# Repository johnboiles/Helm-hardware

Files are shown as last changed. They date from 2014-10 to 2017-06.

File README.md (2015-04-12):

Helm
====
Board to convert RayMarine Seatalk to NMEA 0183 and vice versa. Also provides a connector for a TTL GPS such as SparkFun part #11571. I use it with a Raspberry PI connected over USB to get boat data into OpenCPN.

BOM
---
* 2x DS89C21 Differential CMOS Line Driver
* 1x Sparkfun Pro Micro 5V/16MHz
* 2x 12-pin female 100 mil headers
* 6x .1uF 0603 or 0805 capacitor
* 2x 4 connector 3.5mm screw terminal
* 1x 3 connector 3.5mm screw terminal
* 1x 2 connector 3.5mm screw terminal
* 3x 10k 0603 resistor
* 1x 15k 0603 resistor
* 1x 3.9k 0603 resistor
* 2x SOT-23 NPN transistor
* 1x EM406 (JST-SH) horizontal connector

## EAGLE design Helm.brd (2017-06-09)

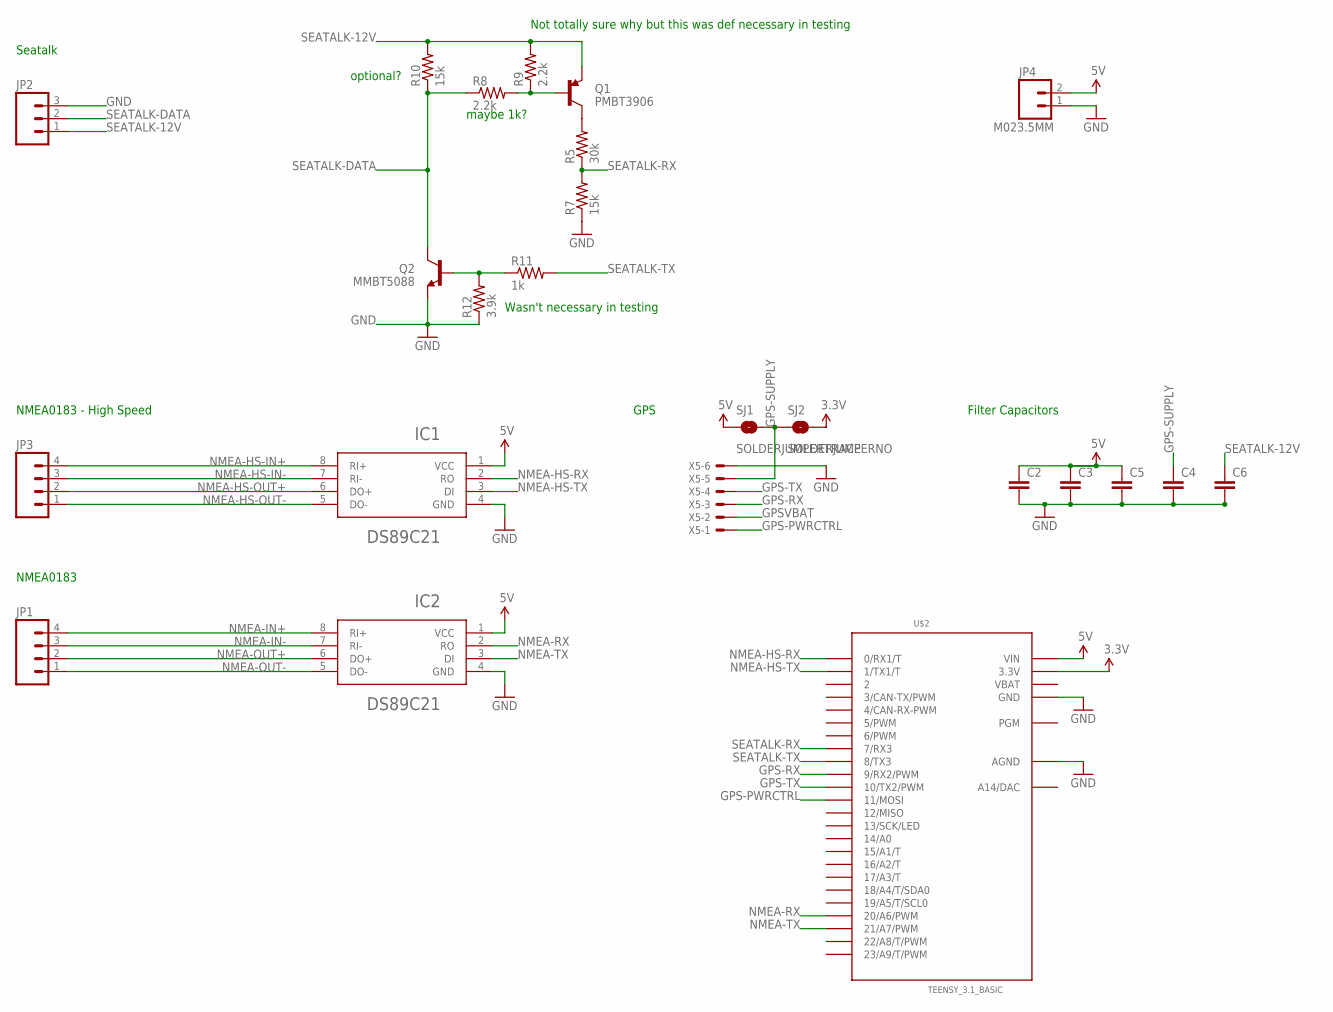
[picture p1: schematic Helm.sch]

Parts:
C2, C3, C4, C5, C6: CAP0805; 0805
IC1, IC2: DS89C21; SO08
JP1, JP3: M04SCREW; SCREWTERMINAL-3.5MM-4
JP2: M03SCREW; SCREWTERMINAL-3.5MM-3
JP4: M023.5MM; SCREWTERMINAL-3.5MM-2
Q1: PMBT3906; SOT23-3
Q2: MMBT5088; SOT23-3
R5: 30k; 0603-RES
R7, R10: 15k; 0603-RES
R8, R9: 2.2k; 0603-RES
R11: 1k; 0603-RES
R12: 3.9k; 0603-RES
SJ1: SOLDERJUMPERTRACE; SJ_2S-TRACE
SJ2: SOLDERJUMPERNO; SJ_2S-NO
U$2: TEENSY_3.1_BASIC
X5: SM06B-SRSS-TB

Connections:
3.3V: SJ2.2, U$2.3.3V, U$2.3.3V1 (3.3V)
5V: C2.1, C3.1, C5.1, IC1.1 (VCC), IC2.1 (VCC), JP4.2, SJ1.1, U$2.VIN
GND: C2.2, C3.2, C4.2, C5.2, C6.2, IC1.4 (GND), IC2.4 (GND), JP2.3, JP4.1, Q2.2 (E), R7.1, R12.1, U$2.AGND, U$2.GND, U$2.GND1 (GND), X5.6
GPS-PWRCTRL: U$2.11 (11/MOSI), X5.1
GPS-RX: U$2.9 (9/RX2/PWM), X5.3
GPS-SUPPLY: C4.1, SJ1.2, SJ2.1, X5.5
GPS-TX: U$2.10 (10/TX2/PWM), X5.4
GPSVBAT: X5.2
unnamed: Q1.3 (C), R5.2
unnamed: Q1.1 (B), R8.2, R9.1
unnamed: Q2.1 (B), R11.1, R12.2
NMEA-HS-IN+: IC1.8 (RI+), JP3.4
NMEA-HS-IN-: IC1.7 (RI-), JP3.3
NMEA-HS-OUT+: IC1.6 (DO+), JP3.2
NMEA-HS-OUT-: IC1.5 (DO-), JP3.1
NMEA-HS-RX: IC1.2 (RO), U$2.0 (0/RX1/T)
NMEA-HS-TX: IC1.3 (DI), U$2.1 (1/TX1/T)
NMEA-IN+: IC2.8 (RI+), JP1.4
NMEA-IN-: IC2.7 (RI-), JP1.3
NMEA-OUT+: IC2.6 (DO+), JP1.2
NMEA-OUT-: IC2.5 (DO-), JP1.1
NMEA-RX: IC2.2 (RO), U$2.20/A6 (20/A6/PWM)
NMEA-TX: IC2.3 (DI), U$2.21/A7 (21/A7/PWM)
SEATALK-12V: C6.1, JP2.1, Q1.2 (E), R9.2, R10.2
SEATALK-DATA: JP2.2, Q2.3 (C), R8.1, R10.1
SEATALK-RX: R5.1, R7.2, U$2.7 (7/RX3)
SEATALK-TX: R11.2, U$2.8 (8/TX3)
VBAT: U$2.VBAT

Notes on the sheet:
Seatalk
NMEA0183 - High Speed
GPS
NMEA0183
Filter Capacitors
optional?
maybe 1k?
Wasn't necessary in testing
Not totally sure why but this was def necessary in testing

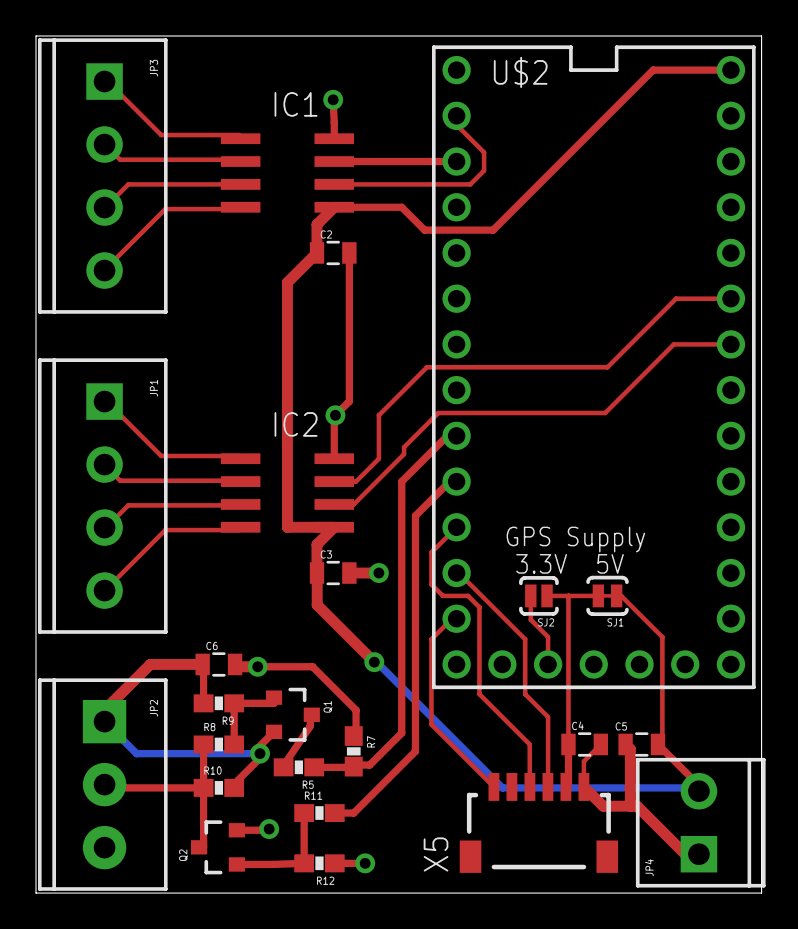
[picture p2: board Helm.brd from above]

Board: 2 copper layers, 40.3 x 47.6 mm, 24 parts (0 on the bottom side), 26 nets.

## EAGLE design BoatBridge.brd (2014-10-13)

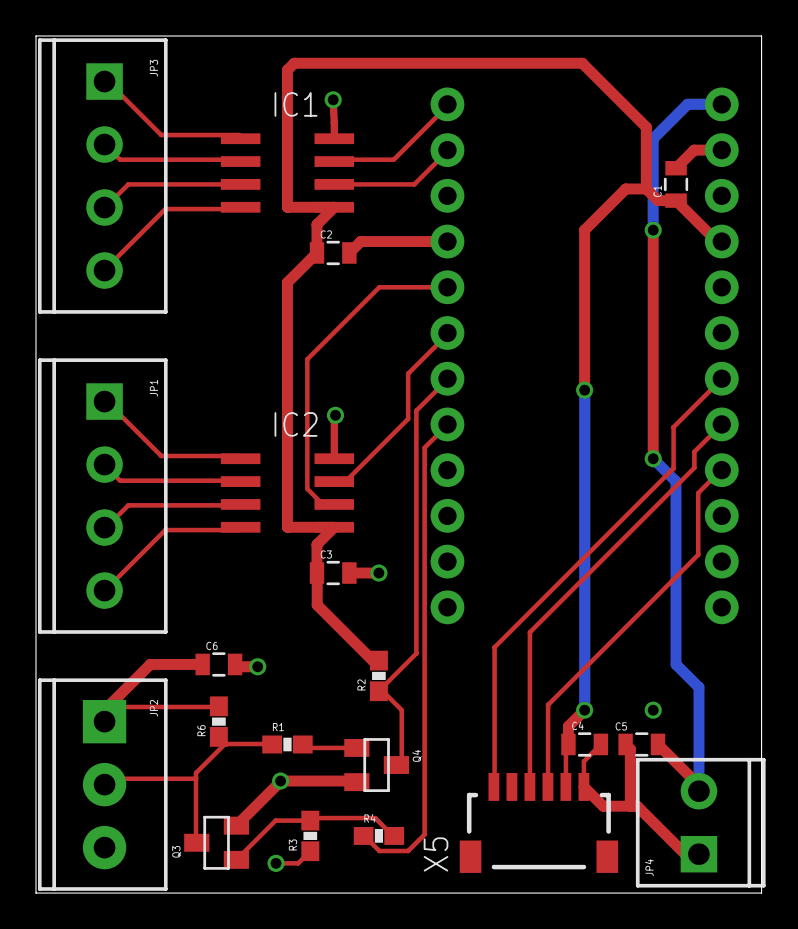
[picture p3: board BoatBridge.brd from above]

Board: 2 copper layers, 40.3 x 47.6 mm, 21 parts (0 on the bottom side), 24 nets.

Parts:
C1, C2, C3, C4, C5, C6: 0805
IC1, IC2: DS89C21; SO08
JP1, JP3: SCREWTERMINAL-3.5MM-4
JP2: SCREWTERMINAL-3.5MM-3
JP4: M023.5MM; SCREWTERMINAL-3.5MM-2
Q3, Q4: SOT23
R1, R2, R4: 10k; 0603-RES
R3: 3.9k; 0603-RES
R6: 15k; 0603-RES
U$1: ARDUINO_PRO_MICRO
X5: SM06B-SRSS-TB

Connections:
5V: C1.1, C2.1, C3.1, C4.1, IC1.1, IC2.1, R2.2, U$1.21, X5.5
GND: C1.2, C2.2, C3.2, C4.2, C5.2, C6.2, IC1.4, IC2.4, JP2.3, JP4.1, Q3.2, Q4.2, R3.1, U$1.3, U$1.4, U$1.23, X5.6
GPS-PWRCTRL: U$1.18, X5.1
GPS-RX: U$1.17, X5.3
GPS-TX: U$1.16, X5.4
unnamed: Q4.1, R1.2
unnamed: Q3.1, R3.2, R4.2
NMEA-HS-IN+: IC1.8, JP3.4
NMEA-HS-IN-: IC1.7, JP3.3
NMEA-HS-OUT+: IC1.6, JP3.2
NMEA-HS-OUT-: IC1.5, JP3.1
NMEA-HS-RX: IC1.2, U$1.2
NMEA-HS-TX: IC1.3, U$1.1
NMEA-IN+: IC2.8, JP1.4
NMEA-IN-: IC2.7, JP1.3
NMEA-OUT+: IC2.6, JP1.2
NMEA-OUT-: IC2.5, JP1.1
NMEA-RX: IC2.2, U$1.5
NMEA-TX: IC2.3, U$1.6
SEATALK-12V: C6.1, JP2.1, R6.2
SEATALK-DATA: JP2.2, Q3.3, R1.1, R6.1
SEATALK-RX: Q4.3, R2.1, U$1.7
SEATALK-TX: R4.1, U$1.8
VRAW: C5.1, JP4.2, U$1.24

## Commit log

2014-10-13 Initial commit -- v1 of board to interface with SeaTalk and NMEA0183
    [BoatBridge.brd, BoatBridge.sch]
2015-04-12 Rename to Helm
    [Helm.brd, Helm.sch]
2017-06-09 v2 of the board. Now using Teensy3.1 for more hardware serial ports.
    [Helm.brd, Helm.sch]

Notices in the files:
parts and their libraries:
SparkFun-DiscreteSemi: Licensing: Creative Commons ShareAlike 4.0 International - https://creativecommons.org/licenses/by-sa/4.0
